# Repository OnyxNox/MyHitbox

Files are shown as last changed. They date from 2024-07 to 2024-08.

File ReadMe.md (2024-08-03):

# My Hitbox
&nbsp; | &nbsp; | &nbsp;
--- | --- | ---
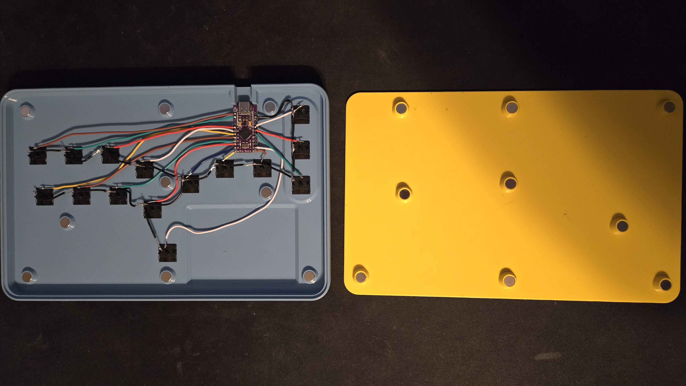
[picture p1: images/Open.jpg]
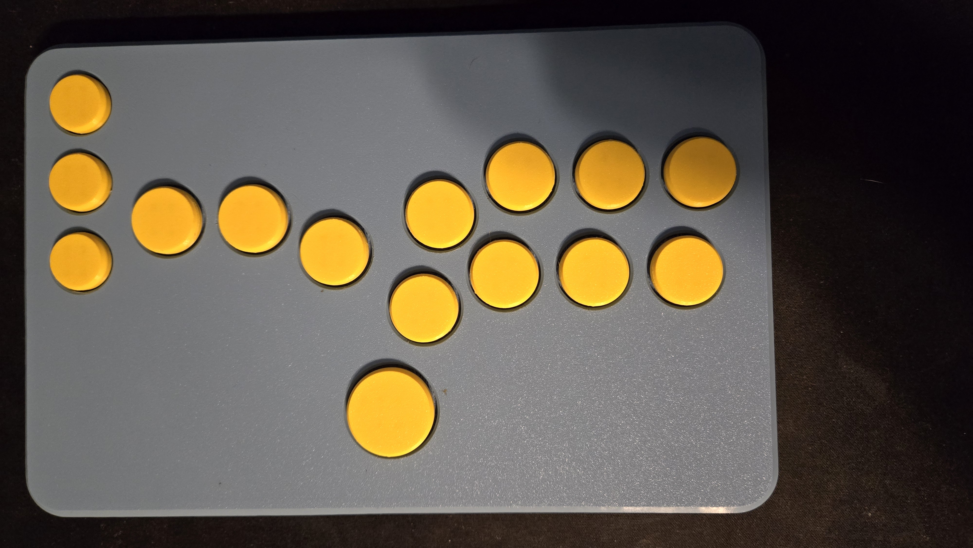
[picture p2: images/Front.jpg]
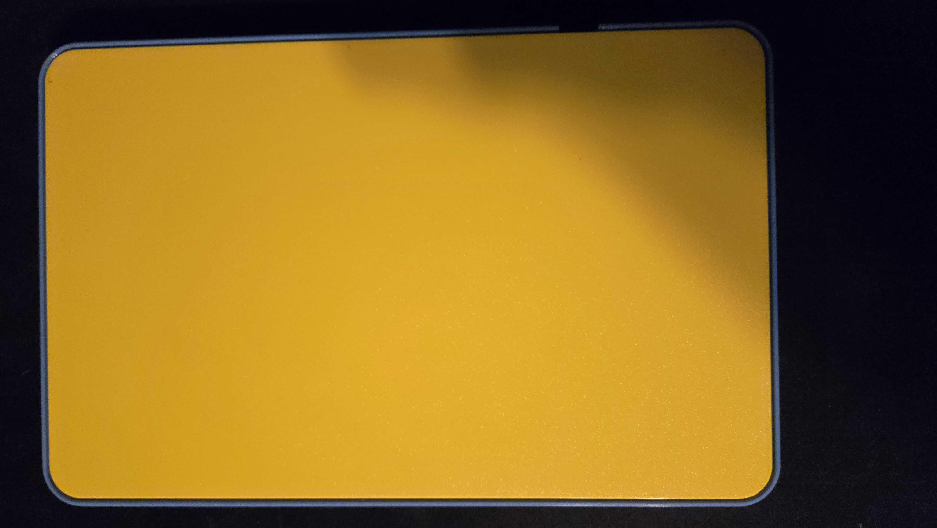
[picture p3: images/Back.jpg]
 |  | 

## Features
- Simultaneous Opposing Cardinal Directions (SOCD) filtering that prioritizes up over down on the vertical axis and is neutral when both left and right are being pressed.

## Hardware Used
- [1x] Arduino Pro Micro
    - Secured to the back of the 3D print using double-sided tape.
- [18x] 3 x 8 mm round magnets
- [15x] Kailh Choc Low Profile Switches (v1)

## 3D Prints
Printed on a Prusa MK4 which has a print volume of 250 x 210 x 220 mm. Total print time for all pieces was about 12 hours.

- [Stickless Slimbox 2040m](https://www.printables.com/model/449392-slimbox-2040-stickless-all-button-low-profile-figh)
    - Modified in [Blender](https://www.blender.org/) to shrink the round magnet housings from 3x10mm to be 3x8mm. Also removed text to reduce the print time.
- [Kailh Choc Arcade Buttons](https://www.printables.com/model/148297-better-printed-arcade-button-kailh-choc-v1-low-pro)

## Flashing Firmware
The steps below are for flashing firmware to an Arduino Pro Micro (Arduino Micro).

1. Download latest [QMK Toolbox](https://github.com/qmk/qmk_toolbox/releases).
1. Open **QMK Toolbox**.
1. Ensure that the correct **MCU (AVR only)** is selected. **Example:** ATmega32U4
1. Click on the **Open** button and select the `MyHitbox.v1.hex` file.
1. Check the **Auto-Flash** checkbox.
1. Reset the board twice in rapid succession to enter the bootloader.
    - I found it may take a few tries to successfully flash the firmware due to the Caterina bootloader.

## Development
- Firmware was developed and built using [Arduino IDE](https://www.arduino.cc/en/software).
- Build HEX file in **Arduino IDE** by navigating to **Sketch** > **Export Compiled Binary**.
    - Alt + Ctrl + S
    - HEX file needed is located at `build/arduino.avr.micro/MyHitbox.ino.hex`.

## Side Quests
### Flashing Corrupted Bootloader
While I was learning about the Arduino Pro Micro's firmware upload process I mistakenly corrupted the Caterina bootloader, bricking the controller. This led me to learn about [Arduino as In-circuit Serial Programmers (ISP)](https://docs.arduino.cc/built-in-examples/arduino-isp/ArduinoISP) which allows for programming of the whole flash memory of the microcontroller, bootloader included, through a specific set of pins connected to a separate programmer board. I had an [ESPWROOM32](https://www.espressif.com/sites/default/files/documentation/esp32-wroom-32_datasheet_en.pdf) laying around to use as a programmer board.

#### Steps Taken
1. In the **Arduino IDE** load the **ArduinoISP** example. It can be found under **File** > **Examples** > **11. Arduino ISP** > **ArduinoISP**.
1. Update the **RESET**, **LED_HB**, **LED_ERR** and **LED_PMODE** pins to be 22, 32, 33 and 25 respectively.
    - **RESET** is originally set to GPIO8 but on the ESP32 pin 8 is for internal SDI. When this pin is used the board enters a bootloop with a TG1WDT_SYS_RESET error.
    - **LED_HB**, **LED_ERR** and **LED_PMODE** are also set to internal pins and need to be reassigned to available output pins to avoid the bootloop.
1. Upload the modified **ArduinoISP** sketch to the ESP32.
1. Hook up the ISP wires between the programmer and target board according to the [Pin Map](#pin-map).
1. Update the target board to be **Arduino Micro**. It can be set under **Tools** > **Board** > **Arduino AVR Boards** > **Arduino Micro**.
1. Set the programmer to be **Arduino as ISP**. It can be found under **Tools** > **Programmer** > **Arduino as ISP**.
1. Burn the bootloader to the target board using the programmer. It can be done from **Tools** > **Burn Bootloader**.

#### Pin Map
Description | ESP32 Pin | Arduino Micro Pin
--- | --- | ---
VCC | VIN | VCC
GND | GND | GND
MISO | 19 | 14
MOSI | 23 | 16
SCK | 18 | 15
RESET | 22 | RST

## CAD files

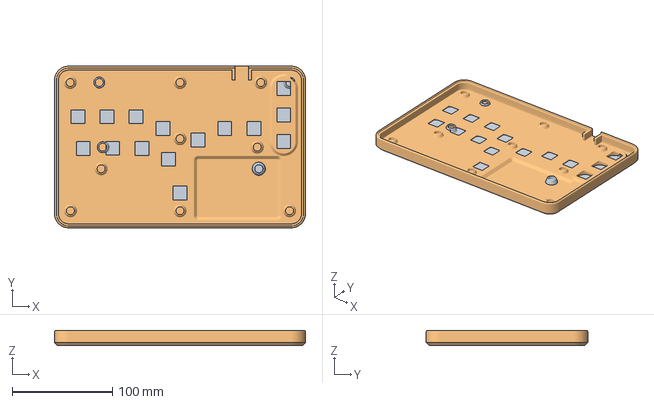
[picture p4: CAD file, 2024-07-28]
Slimbox2040m.3mf
250.0 x 161.0 x 15.4 mm
Bottom.stl
Case.stl

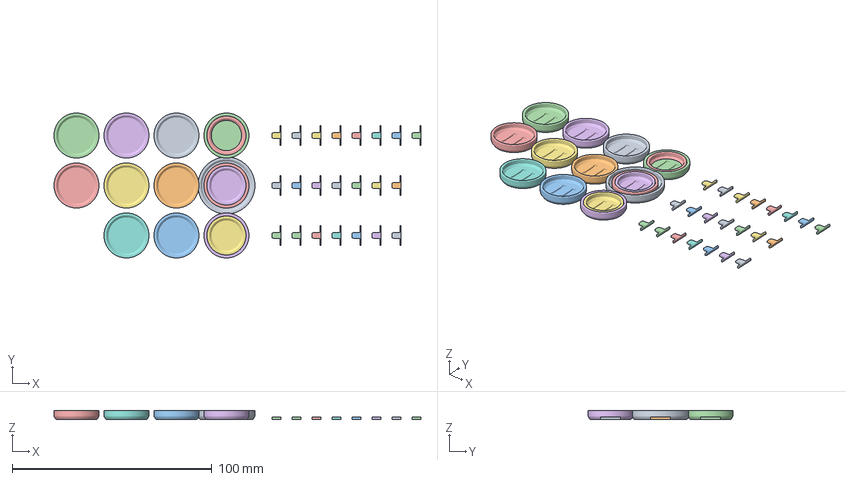
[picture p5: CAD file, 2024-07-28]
Kailh Choc Arcade Buttons.3mf
183.5 x 72.5 x 4.40 mm
Kailh_Choc_28.5mm_Cap.stl
Kailh_Choc_1.3mm_by_2.9mm_Leg.stl x 3
Kailh_Choc_22.5mm_Cap.stl
Kailh_Choc_19.5mm_Cap.stl

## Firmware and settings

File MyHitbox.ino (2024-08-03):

#include <Keyboard.h>

#define UP_BUTTON_PIN      16
#define DOWN_BUTTON_PIN     9
#define LEFT_BUTTON_PIN    10
#define RIGHT_BUTTON_PIN    8
#define X_BUTTON_PIN        3
#define Y_BUTTON_PIN        2
#define A_BUTTON_PIN        7
#define B_BUTTON_PIN        6
#define R1_BUTTON_PIN       0
#define R2_BUTTON_PIN       5
#define L1_BUTTON_PIN       1
#define L2_BUTTON_PIN       4
#define EXTRA_1_BUTTON_PIN 19
#define EXTRA_2_BUTTON_PIN 20
#define EXTRA_3_BUTTON_PIN 21

#define UP_BUTTON_ASCII      119  // w
#define DOWN_BUTTON_ASCII    115  // s
#define LEFT_BUTTON_ASCII     97  // a
#define RIGHT_BUTTON_ASCII   100  // d
#define X_BUTTON_ASCII       117  // u
#define Y_BUTTON_ASCII       105  // i
#define A_BUTTON_ASCII       106  // j
#define B_BUTTON_ASCII       107  // k
#define R1_BUTTON_ASCII      111  // o
#define R2_BUTTON_ASCII      108  // l
#define L1_BUTTON_ASCII      112  // p
#define L2_BUTTON_ASCII       59  // ;
#define EXTRA_1_BUTTON_ASCII  10  // (enter) line feed
#define EXTRA_2_BUTTON_ASCII  92  // (\) backslash
#define EXTRA_3_BUTTON_ASCII   8  // backspace

struct Button
{
    unsigned int Pin;
    unsigned int AsciiOutput;
    unsigned int State;
    unsigned int PreviousState;
};

Button buttons[15] =
{
    { UP_BUTTON_PIN     , UP_BUTTON_ASCII     , HIGH, HIGH },
    { DOWN_BUTTON_PIN   , DOWN_BUTTON_ASCII   , HIGH, HIGH },
    { LEFT_BUTTON_PIN   , LEFT_BUTTON_ASCII   , HIGH, HIGH },
    { RIGHT_BUTTON_PIN  , RIGHT_BUTTON_ASCII  , HIGH, HIGH },
    { X_BUTTON_PIN      , X_BUTTON_ASCII      , HIGH, HIGH },
    { Y_BUTTON_PIN      , Y_BUTTON_ASCII      , HIGH, HIGH },
    { A_BUTTON_PIN      , A_BUTTON_ASCII      , HIGH, HIGH },
    { B_BUTTON_PIN      , B_BUTTON_ASCII      , HIGH, HIGH },
    { R1_BUTTON_PIN     , R1_BUTTON_ASCII     , HIGH, HIGH },
    { R2_BUTTON_PIN     , R2_BUTTON_ASCII     , HIGH, HIGH },
    { L1_BUTTON_PIN     , L1_BUTTON_ASCII     , HIGH, HIGH },
    { L2_BUTTON_PIN     , L2_BUTTON_ASCII     , HIGH, HIGH },
    { EXTRA_1_BUTTON_PIN, EXTRA_1_BUTTON_ASCII, HIGH, HIGH },
    { EXTRA_2_BUTTON_PIN, EXTRA_2_BUTTON_ASCII, HIGH, HIGH },
    { EXTRA_3_BUTTON_PIN, EXTRA_3_BUTTON_ASCII, HIGH, HIGH },
};

const unsigned int buttonsCount = sizeof(buttons) / sizeof(buttons[0]);

Button* const UP_BUTTON_PTR    = &buttons[0];
Button* const DOWN_BUTTON_PTR  = &buttons[1];
Button* const LEFT_BUTTON_PTR  = &buttons[2];
Button* const RIGHT_BUTTON_PTR = &buttons[3];

unsigned int i;
unsigned int tempLeftButtonState = HIGH;

void setup()
{
    for (i = 0; i < buttonsCount; i++)
    {
        pinMode(buttons[i].Pin, INPUT_PULLUP);
    }

    Keyboard.begin();
}

void loop()
{
    // set all buttons current state
    for (i = 0; i < buttonsCount; i++)
    {
        buttons[i].State = digitalRead(buttons[i].Pin);
    }

    // vertical Simultaneous Opposing Cardinal Directions (SOCD) filter
    DOWN_BUTTON_PTR->State = DOWN_BUTTON_PTR->State == LOW && UP_BUTTON_PTR->State == HIGH
        ? LOW : HIGH;

    // horizontal SOCD filter
    tempLeftButtonState = LEFT_BUTTON_PTR->State == LOW && RIGHT_BUTTON_PTR->State == LOW
        ? HIGH : LEFT_BUTTON_PTR->State;
    RIGHT_BUTTON_PTR->State = RIGHT_BUTTON_PTR->State == LOW && LEFT_BUTTON_PTR->State == LOW
        ? HIGH : RIGHT_BUTTON_PTR->State;
    LEFT_BUTTON_PTR->State = tempLeftButtonState;

    for (i = 0; i < buttonsCount; i++)
    {
        if (buttons[i].State != buttons[i].PreviousState)
        {
            if (buttons[i].State == LOW)
            {
                Keyboard.press(buttons[i].AsciiOutput);
            }
            else
            {
                Keyboard.release(buttons[i].AsciiOutput);
            }
        }
    }

    // set all buttons previous state
    for (i = 0; i < buttonsCount; i++)
    {
        buttons[i].PreviousState = buttons[i].State;
    }
}
